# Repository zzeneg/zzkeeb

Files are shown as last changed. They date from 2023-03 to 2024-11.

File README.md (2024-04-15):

# zzkeeb

Shared library for my keyboard components

## KiCad

#### Installation
Go to KiCad, `Preferences` -> `Configure Paths`, add new row with name `ZZKEEB` and path to `zzkeeb/kicad`



#### Included projects

- https://github.com/sadekbaroudi/fingerpunch
- https://github.com/foostan/kbd
- https://github.com/crides/kleeb
- https://github.com/keebio/Keebio-Parts.pretty
- https://github.com/0xCB-dev/0xCB-libs
- https://github.com/Fooblitzky/DCS_keycaps.git

#### Additional 3D models

- [Encoder knob](https://grabcad.com/library/knob-85)
- [11mm rotary encoder](https://grabcad.com/library/11mm-metal-shaft-rotary-encoders-tht-vertical-w-push-on-switch-1)
- [ChocV1 socket](https://grabcad.com/library/kailh-1350-socket-2)
- [FFC horizontal 12p](https://grabcad.com/library/fpc-ffc-1)
- [KS-33 switch/socket](https://github.com/DeltaWhy/ols)
- [5way switch](https://grabcad.com/library/5-way-tactile-button-tht-1)
- [JST 12pin 1.25 connectors](https://grabcad.com/library/jst-gh-1-25mm-connector-set-1)

## Custom 3D models

- choc opener, just sprued two models from https://www.thingiverse.com/thing:3097933

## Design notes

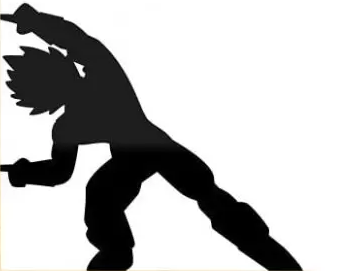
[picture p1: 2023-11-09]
kicad/images/fusion-dance-right.png

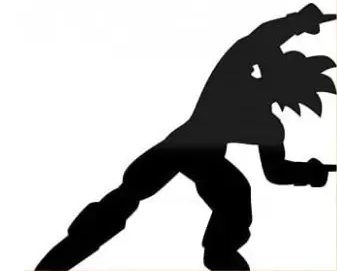
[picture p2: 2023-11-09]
kicad/images/fusion-dance-left.png

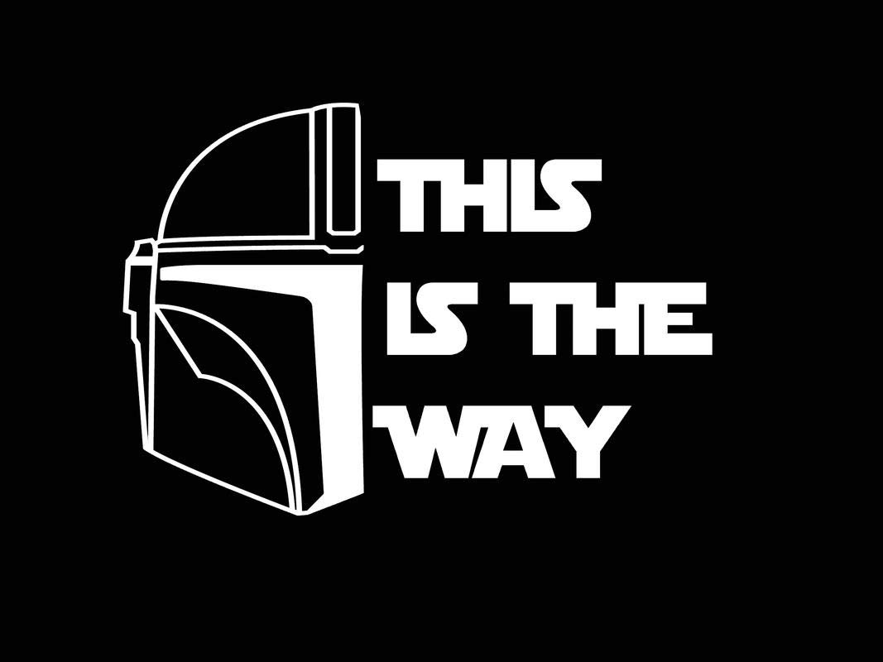
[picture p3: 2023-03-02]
kicad/images/way.jpg

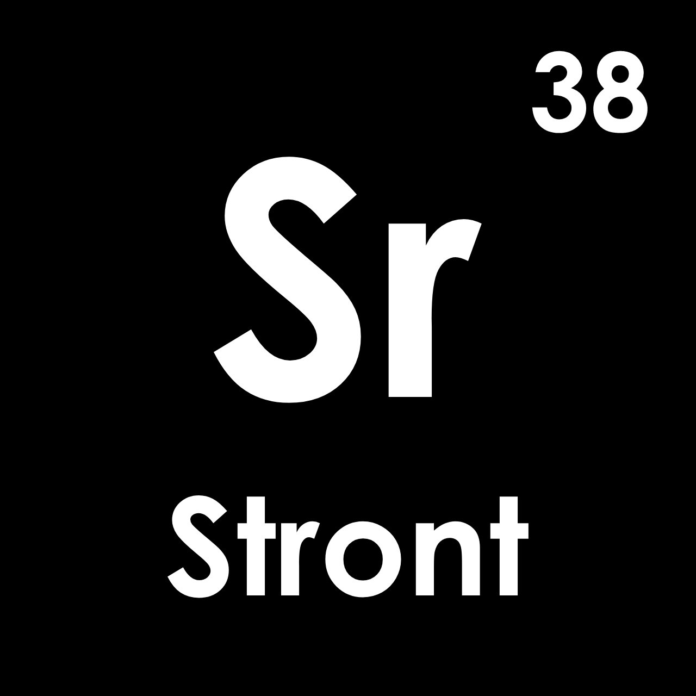
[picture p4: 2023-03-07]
kicad/images/stront.png

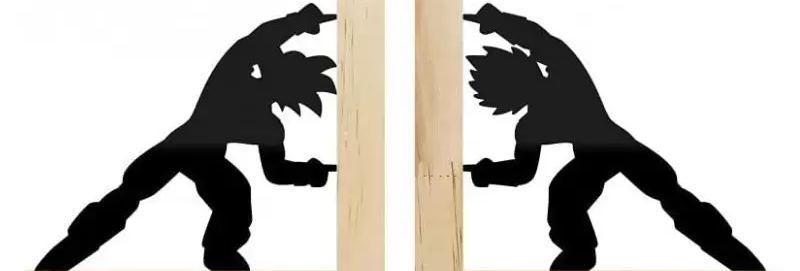
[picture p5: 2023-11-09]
kicad/images/fusion-dance.png

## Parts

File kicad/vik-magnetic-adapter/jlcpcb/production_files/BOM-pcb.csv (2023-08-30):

Comment | Designator | Footprint | LCSC
Connector_VIK-keyboard | VIK_K5 | Connector_VIK-horizontal-keyboard
Connector_VIK-keyboard | VIK_K4 | Connector_VIK-horizontal-keyboard
Connector_VIK-keyboard | VIK_K3 | Connector_VIK-vertical-keyboard
Connector_VIK-keyboard | VIK_K2 | Connector_VIK-vertical-keyboard
Connector_VIK-keyboard | VIK_K1 | Connector_VIK-magnetic-keyboard

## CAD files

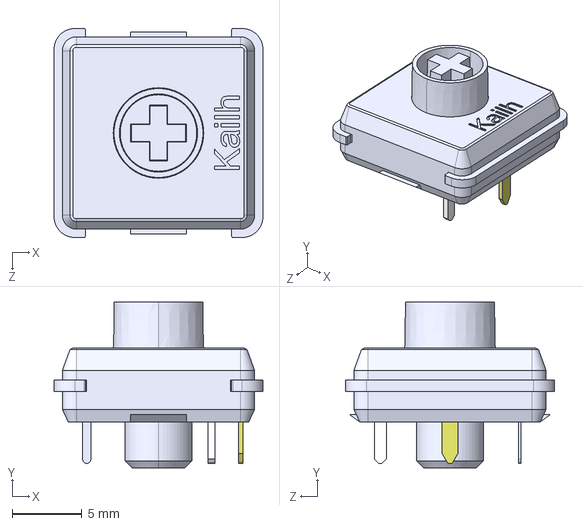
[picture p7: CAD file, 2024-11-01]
kicad/models/Kailh_PG1353.STEP
15.0 x 11.9 x 15.0 mm

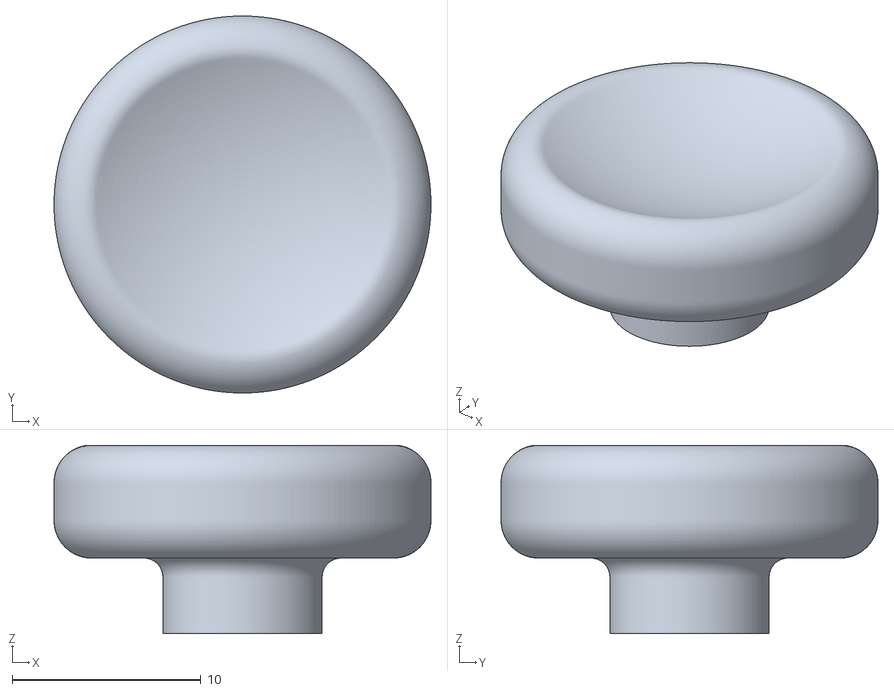
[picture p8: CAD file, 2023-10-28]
stl/5way-concave-knob-cut-4mm-stem-4mm.stl
20.0 x 20.0 x 9.98

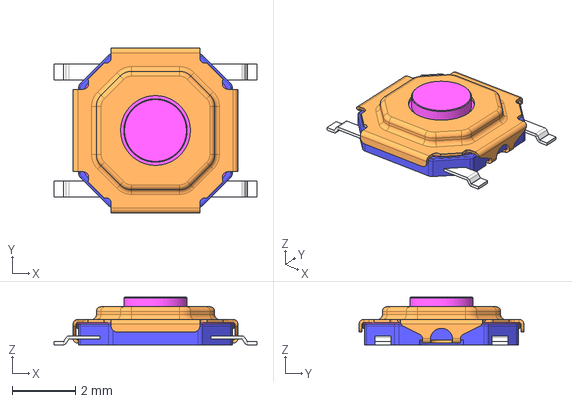
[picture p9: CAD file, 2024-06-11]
kicad/models/Button_SW_SPST_SKQG_WithoutStem.STEP
6.40 x 5.20 x 1.50 mm

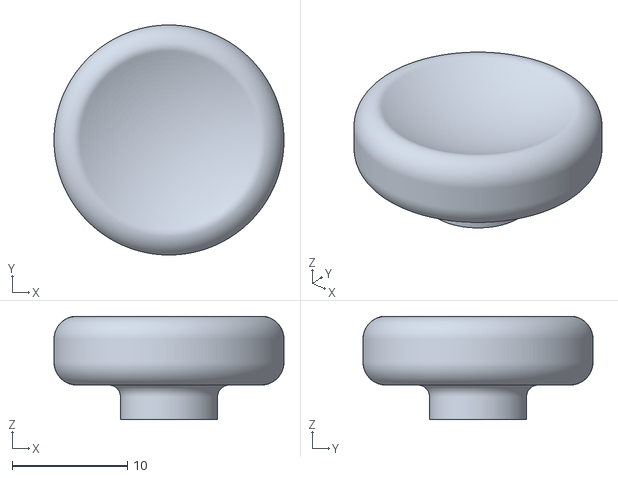
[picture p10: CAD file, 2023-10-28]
stl/5way-concave-knob-cut-4mm-stem-3mm.stl
20.0 x 20.0 x 8.98

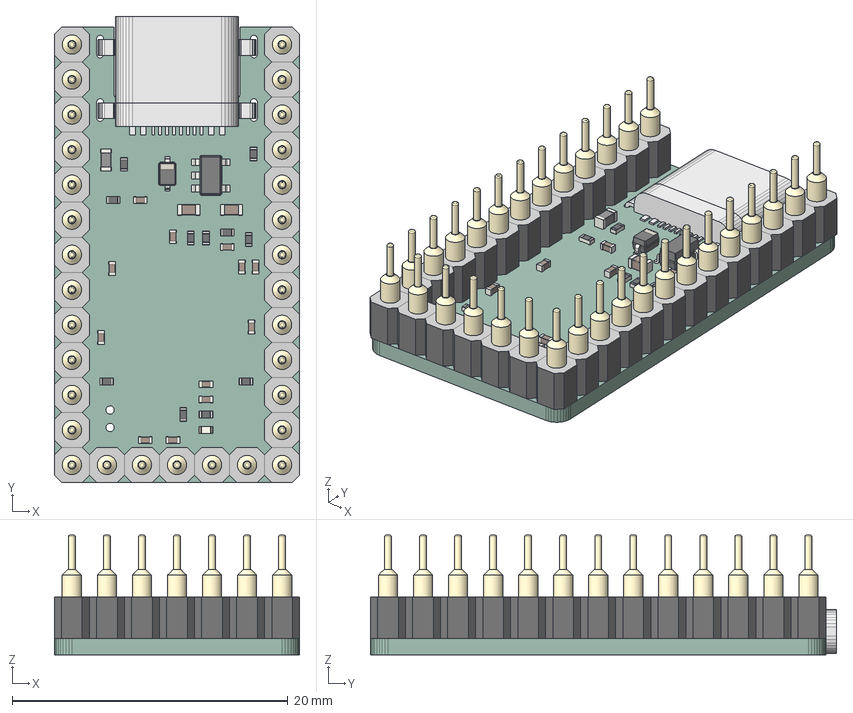
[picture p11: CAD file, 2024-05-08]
kicad/models/splinky-headers.step
17.8 x 33.8 x 8.68 mm
0xB2 PCB
Header-Female-round x 31

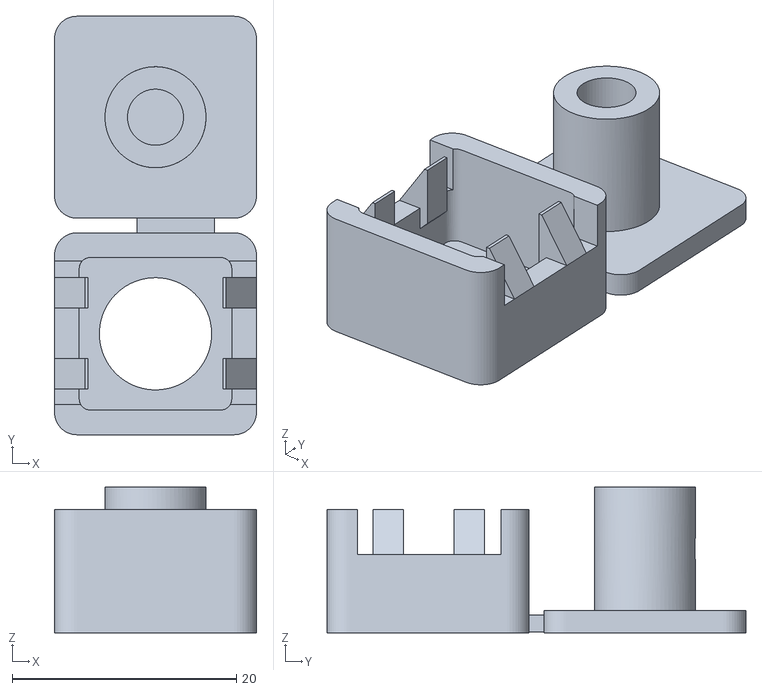
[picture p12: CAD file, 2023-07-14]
stl/ChocOpener.stl
18.0 x 37.3 x 13.0

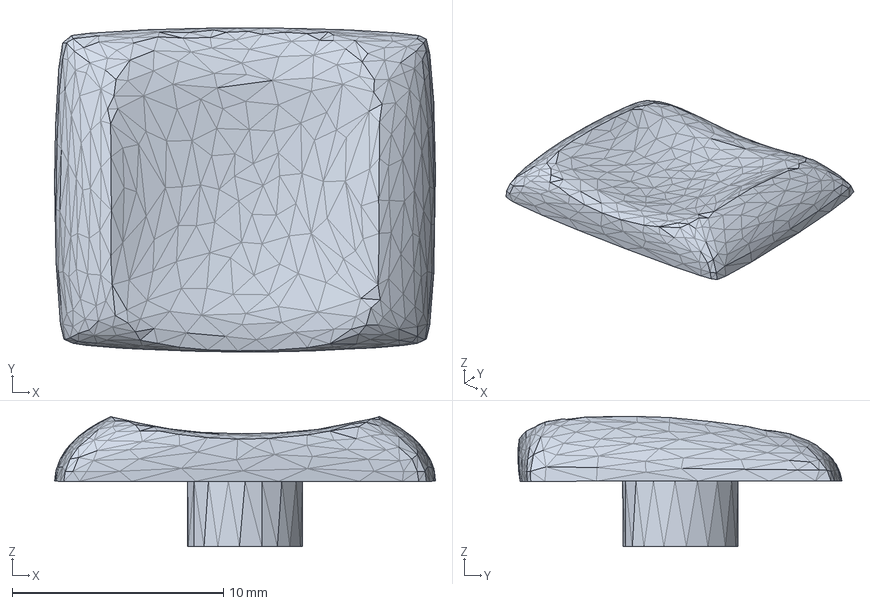
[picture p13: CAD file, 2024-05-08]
kicad/models/Keycap_MX-DES-minY-minZ-R3.step
18.0 x 15.3 x 6.16 mm

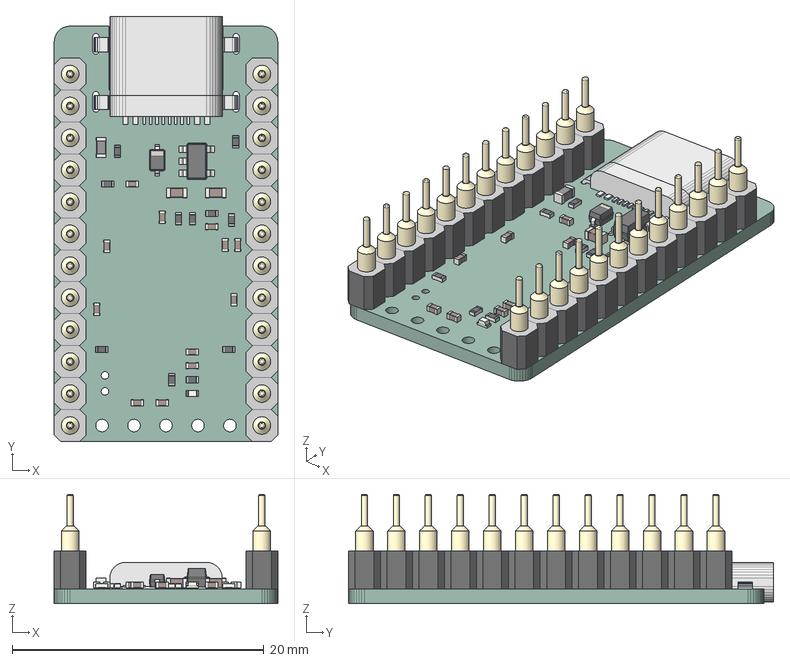
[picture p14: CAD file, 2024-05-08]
kicad/models/splinky-side-headers.step
17.8 x 33.8 x 8.68 mm
0xB2 PCB
Header-Female-round x 24

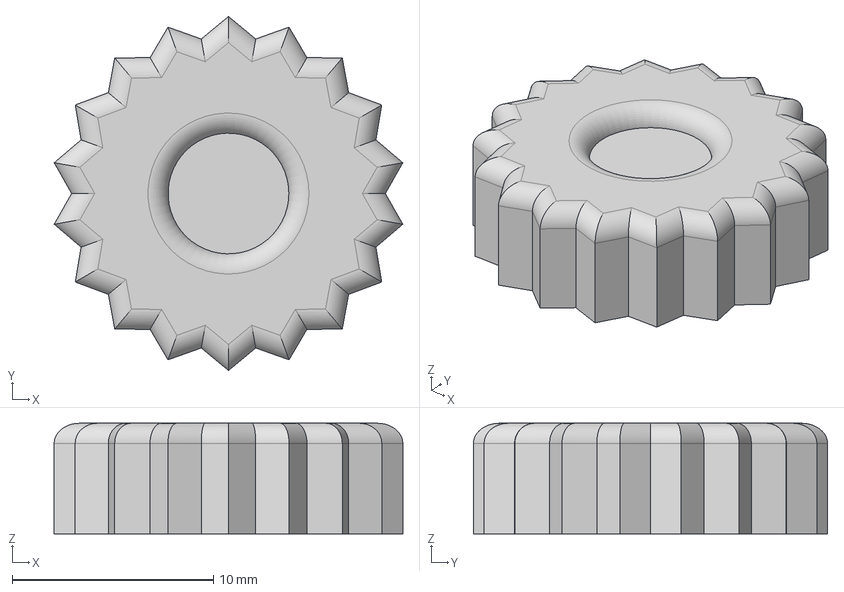
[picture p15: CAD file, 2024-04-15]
kicad/models/EC12LP v10.step
17.3 x 17.6 x 5.50 mm

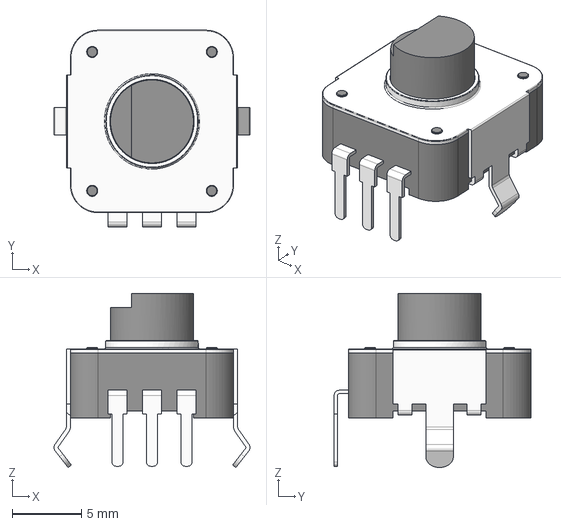
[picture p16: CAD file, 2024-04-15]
kicad/models/EC12 Encoder short.step
14.2 x 14.2 x 12.6 mm

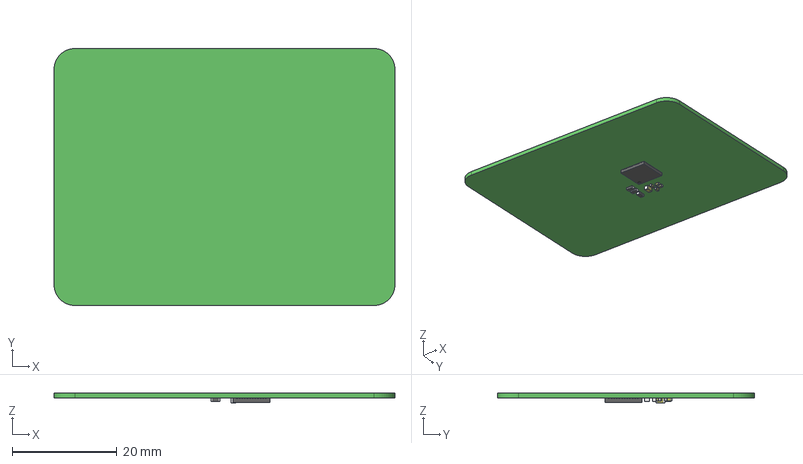
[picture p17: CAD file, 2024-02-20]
kicad/models/Touchpad_Azoteq-TPS65.step
65.0 x 49.0 x 1.95 mm
C-0402 x 4
C-0603
R-0603 x 3
U-QFN-P0.5-7X7-48

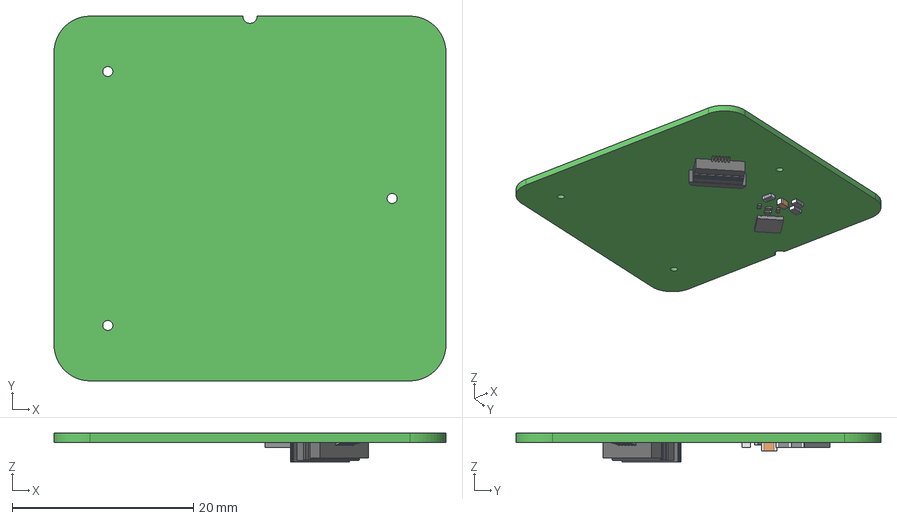
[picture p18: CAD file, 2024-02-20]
kicad/models/Touchpad_Azoteq-TPS43.step
43.3 x 40.3 x 3.15 mm
6PinFPC_-_Pins x 6
6PinFPC_-_Body
C-0402 x 4
C-0603
R-0603 x 3
U-QFN-P0.5-4X4-28

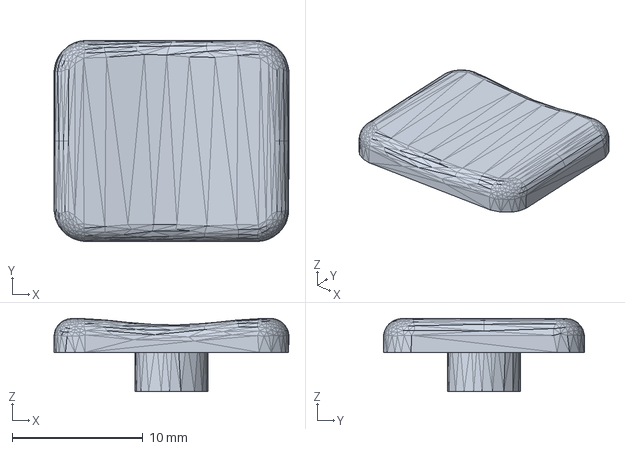
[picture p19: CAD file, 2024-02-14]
kicad/models/Keycap_MX-CMY-R3.step
18.0 x 15.4 x 5.60 mm

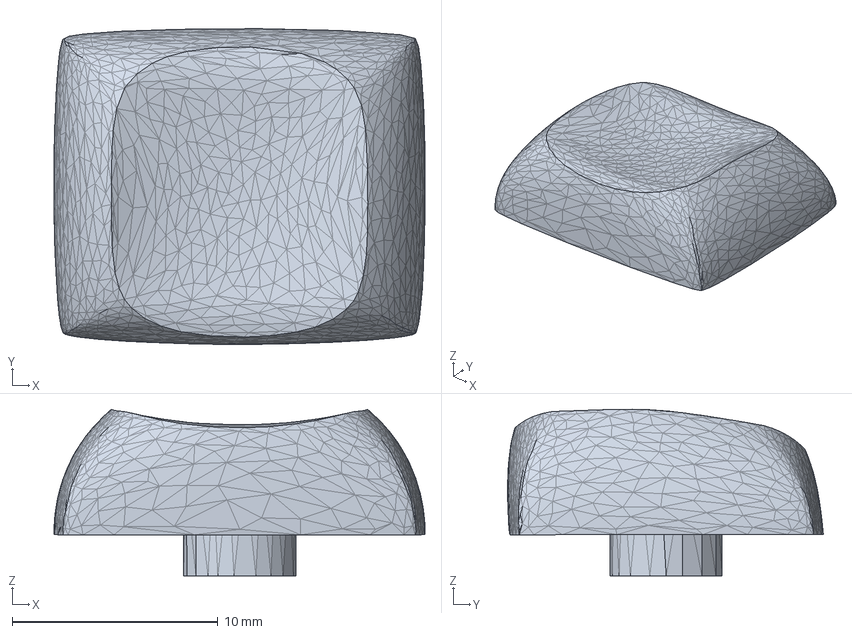
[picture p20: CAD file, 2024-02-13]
kicad/models/Keycap_MX-DES-minY-R3.step
18.0 x 15.3 x 8.09 mm

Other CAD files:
kicad/models/FPC 6-PIN SMD.stp
kicad/models/vik-azoteq-adapter-vertical.step
kicad/models/PMW3360 v12.step
kicad/models/CMY-MX-R3.step
fusion360/Cirque40mm v4.f3z
kicad/models/5-WayTactileButton10mmTHT.stp
kicad/models/5-way-concave-short.step
kicad/models/Button_5way-SKRHABE010-concave-short.step
kicad/models/Button_5way-SKRHABE010.stp
kicad/models/Display 1.69 ST7789V2.step
kicad/models/EC11-THT-15F-black.step
kicad/models/EC12 Encoder 10mm 3pin.stp
kicad/models/FPC vertical connector-1mm-10PIN.STEP
kicad/models/FPC-12.stp
kicad/models/JST - GH - SMD (R) - 12Pin - 1.25mm.stp
kicad/models/JST - GH - SMD (V) - 12Pin - 1.25mm.stp
kicad/models/Magnetic connector 12pin female.step
kicad/models/Magnetic connector 12pin male.step
kicad/models/PG1350-socket.STEP
kicad/models/RotaryEncKnob.STEP
kicad/models/Seeed Studio XIAO RP2040 v26.step
kicad/models/TM040040_Overlay.STEP
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

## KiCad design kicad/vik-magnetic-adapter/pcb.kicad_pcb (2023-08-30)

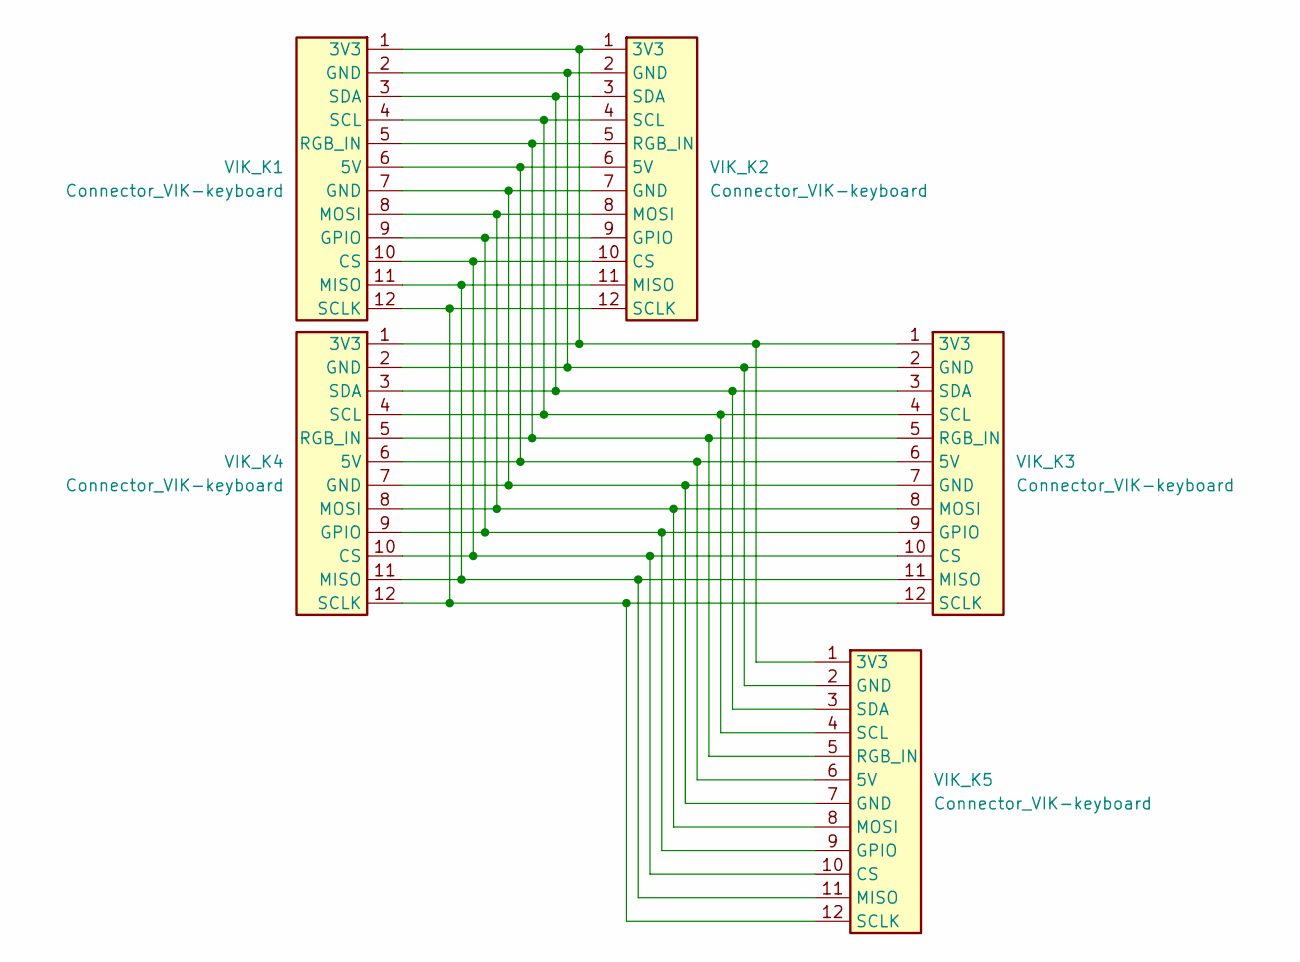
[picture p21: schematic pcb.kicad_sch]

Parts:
VIK_K1: Connector_VIK-keyboard; Connector_VIK-magnetic-keyboard
VIK_K2, VIK_K3: Connector_VIK-keyboard; Connector_VIK-vertical-keyboard
VIK_K4, VIK_K5: Connector_VIK-keyboard; Connector_VIK-horizontal-keyboard

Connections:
unnamed: VIK_K1.1 (3V3), VIK_K2.1 (3V3), VIK_K3.1 (3V3), VIK_K4.1 (3V3), VIK_K5.1 (3V3)
unnamed: VIK_K1.6 (5V), VIK_K2.6 (5V), VIK_K3.6 (5V), VIK_K4.6 (5V), VIK_K5.6 (5V)
unnamed: VIK_K1.10 (CS), VIK_K2.10 (CS), VIK_K3.10 (CS), VIK_K4.10 (CS), VIK_K5.10 (CS)
unnamed: VIK_K1.2 (GND), VIK_K2.2 (GND), VIK_K3.2 (GND), VIK_K4.2 (GND), VIK_K5.2 (GND)
unnamed: VIK_K1.7 (GND), VIK_K2.7 (GND), VIK_K3.7 (GND), VIK_K4.7 (GND), VIK_K5.7 (GND)
unnamed: VIK_K1.9 (GPIO), VIK_K2.9 (GPIO), VIK_K3.9 (GPIO), VIK_K4.9 (GPIO), VIK_K5.9 (GPIO)
unnamed: VIK_K1.11 (MISO), VIK_K2.11 (MISO), VIK_K3.11 (MISO), VIK_K4.11 (MISO), VIK_K5.11 (MISO)
unnamed: VIK_K1.8 (MOSI), VIK_K2.8 (MOSI), VIK_K3.8 (MOSI), VIK_K4.8 (MOSI), VIK_K5.8 (MOSI)
unnamed: VIK_K1.5 (RGB_IN), VIK_K2.5 (RGB_IN), VIK_K3.5 (RGB_IN), VIK_K4.5 (RGB_IN), VIK_K5.5 (RGB_IN)
unnamed: VIK_K1.4 (SCL), VIK_K2.4 (SCL), VIK_K3.4 (SCL), VIK_K4.4 (SCL), VIK_K5.4 (SCL)
unnamed: VIK_K1.12 (SCLK), VIK_K2.12 (SCLK), VIK_K3.12 (SCLK), VIK_K4.12 (SCLK), VIK_K5.12 (SCLK)
unnamed: VIK_K1.3 (SDA), VIK_K2.3 (SDA), VIK_K3.3 (SDA), VIK_K4.3 (SDA), VIK_K5.3 (SDA)

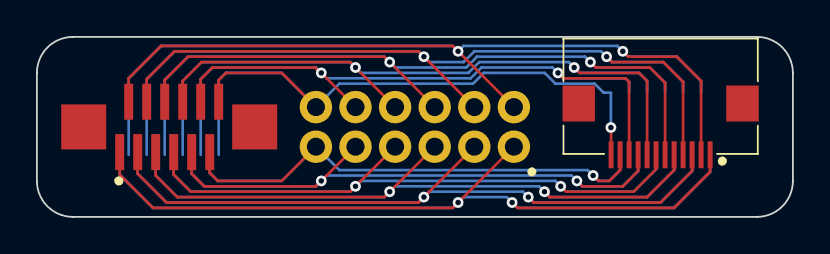
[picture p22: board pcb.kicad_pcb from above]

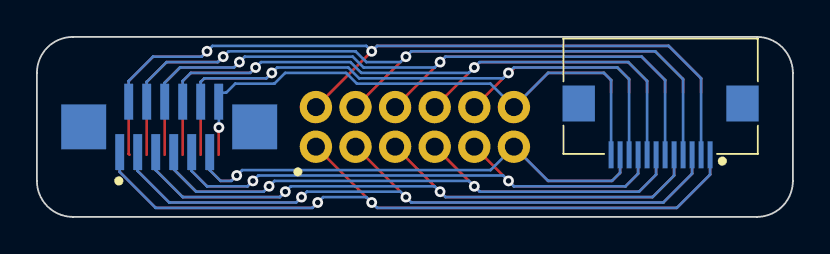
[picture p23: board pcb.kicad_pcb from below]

Board: 2 copper layers, 42.0 x 10.0 mm, 5 parts (2 on the bottom side), 12 nets.

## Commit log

2023-01-15 add kicad components
2023-02-03 improve choc footprint
2023-02-03 add kicad libraries
2023-02-03 more non-reversible footprints
2023-02-03 improve 3d
    [2169900001.stp, D_SOD-123 Soldered.step, EVQWGD001.step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]
2023-02-04 improve encoders and cirque
    [Rotary Encoder.step, ec11.STEP]
2023-02-04 add choc socket model
    [PG1350-socket.STEP]
2023-02-05 experimental ffc-fpc footprints
2023-02-05 8 pin connector
2023-02-06 improve mid mount
2023-02-09 update footprints after testing
2023-02-16 MX 3d models
    [Row_2_1.5u.step, Row_2_1u.step, SW_Cherry_MX_PCB.step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]
2023-02-16 use original 3d models
    [2169900001.stp, D_SOD-123 Soldered.step, EVQWGD001.step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]
2023-02-16 add more XIAO symbols/footprints
    [Seeed Studio XIAO RP2040 v26.step]
2023-02-17 fix MXChocV2 footprints
2023-02-18 fix pica logo footprint
2023-02-21 new test components
    [Display 1.69 ST7789V2.step, FPC vertical connector-1mm-10PIN.STEP]
2023-02-24 update usb connector
2023-02-26 improve rotary encoder
    [EC11-THT-15F-black.step, RotaryEncKnob.STEP]
2023-03-01 improve ffc connector
2023-05-31 add gateron ks27/ks33 footprint
2023-06-02 improve ks switches
2023-06-03 add labeled symbols/footprints
2023-06-05 fix adapter footprint
2023-06-05 add ks-33 3D models and cutouts
    [ks33.step, ks33_socket.step]
2023-06-14 update VIK footprints
    [FPC-12.stp, c-1-1734742-2-o-3d.stp]
2023-06-14 add fingerpunch lib
2023-07-07 increase font size, fix led
2023-07-14 add choc opener
    [ChocOpener.stl]
2023-08-13 add VIK adapter for magnetic connector
2023-08-19 5way switch and 6mm push button
    [5-WayTactileButton10mmTHT.stp, 5-way-concave-short.step]
2023-08-26 improve reversible footprints
2023-08-27 fix diodes 3D models
2023-08-30 add magnetic adapter pcb
    [BOM-pcb.csv, pcb.kicad_pcb, pcb.kicad_sch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]
2023-09-01 update 5way knob
    [5-way-concave-short.step]
2023-09-04 add 3d models for magnetic connectors
    [Magnetic connector 12pin female.step, Magnetic connector 12pin male.step]
2023-09-07 MCU footprints
2023-09-16 fix 5way reversible footprints
    [5-way-concave-short.step]
2023-09-22 update 5way knobs
    [5way-concave-knob-cut-4mm-stem-3mm.stl, 5way-concave-knob-cut-4mm-stem-4mm.stl]
2023-10-28 improve rp zero footprint and choc cutout
2023-11-01 wireless components
    [niceview.step, splinky.step]
2023-11-02 12 pin jst connectors
    [JST - GH - SMD (R) - 12Pin - 1.25mm.stp, JST - GH - SMD (V) - 12Pin - 1.25mm.stp]
2023-11-05 add SW_SPST_SKQG_WithoutStem
    [Button_SW_SPST_SKQG_WithoutStem.STEP]
2023-11-05 add Alps 5way
    [Button_5way-SKRHABE010-concave-short.step, Button_5way-SKRHABE010.stp]
2023-11-25 add FFC 12pin 1mm connector
2023-11-28 add FFC 12pin 1mm horizontal connector
2023-11-28 update 12pin connectors
2023-12-09 improve nice-nano footprint
2023-12-11 add ec12 model
    [EC12 Encoder 10mm 3pin.stp]
2024-01-08 add KS-minY footprint
    [CMY-MX-R3.step]
2024-01-15 add pmw3360 model
    [PMW3360 v12.step]
2024-02-03 add azoteq 3d models
    [FPC 6-PIN SMD.stp, azoteq-tps65.step, vik-azoteq-adapter-vertical.step]
2024-02-03 add s8050 and solder nut
    [solder-nut-4x5x2.5x1.5.step]
2024-02-03 add display 12pin connector
2024-02-08 update Cirque 40mm model
    [Cirque40mm v4.f3z]
2024-02-09 add display connector 0.8mm pitch
2024-02-10 improve xiao footprints
2024-02-10 improve diode footprints
2024-02-13 add MX minY footprints
    [Keycap_MX-DES-minY-R3.step]
2024-02-14 add KS minY reversible
    [Keycap_MX-CMY-R3.step]
2024-02-14 diode footprints without labels
2024-02-14 fix reversible footprints
2024-02-16 mirrored footprints
2024-02-20 official azoteq models
    [Touchpad_Azoteq-TPS43.step, Touchpad_Azoteq-TPS65.step, azoteq-tps65.step]
2024-02-24 update solder nut footprint
2024-04-15 - KiCad 8 - add helios-like MCU footprint - add generic 12pin FFC connector footprints - improve minY footprints - add EC12 models
    [EC12 Encoder short.step, EC12LP v10.step]
2024-04-24 update VIK connectors
2024-05-08 new footprints and models
    [Keycap_MX-DES-minY-minZ-R3.step, splinky-headers.step, splinky-side-headers.step]
2024-05-30 enlarge M2 holes
2024-06-11 fix reset button 3d model
    [Button_SW_SPST_SKQG_WithoutStem.STEP]
2024-11-01 add mx-ks-chocV2 footprint
    [Kailh_PG1353.STEP]
